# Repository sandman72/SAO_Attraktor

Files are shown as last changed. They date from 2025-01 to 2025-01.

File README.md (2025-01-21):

# SAO_Attraktor
Attraktor Logo as a SAO (Shitty / Supercon Add On)

Runs pixel animations on the Attraktor SAO Badge's 42 (! of course) LEDs

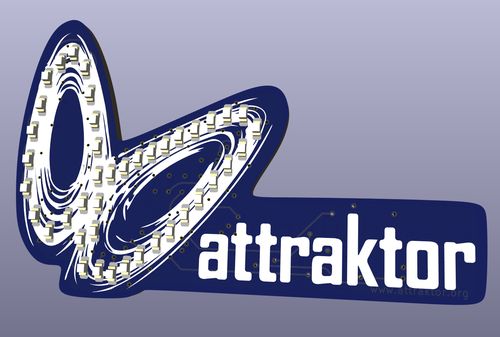
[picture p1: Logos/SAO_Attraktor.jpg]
SAO_Front

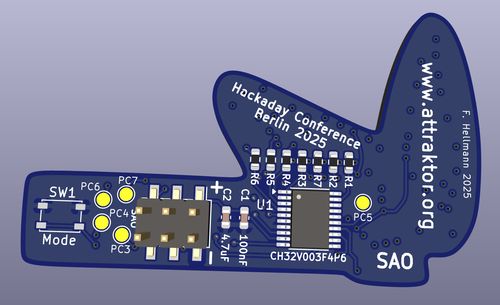
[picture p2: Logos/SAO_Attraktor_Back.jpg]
SAO_Back


KiCAD 8.0 Project with Schematics, PCB, Gerbers and Testcode 
for the Attraktor SAO PCB we show at the Hackaday Conference 2025.

Runs pixel animations on the Attraktor SAO Badge's 42 (! of course) LEDs

The Arduino code works with the following CH32V003 MCUs from the board manager:
  - CH32 MCU EVT Boards 1.0.4 or later (WCHLinkRV driver)
  - or WCH32 Boards 0.0.2 (WinUSB driver) 

Upload needs the CH32V003 WCH-LinkE dongle in RISC-V mode.

For the SAO Board to work correctly you need to reflash the MCU 
with the WCH-LinkUtility once to disable the NRST functionality on pin PD7:

  "Disable mul-func, PD7 is used for IO func"

Beware that the Eval Boards use pin PA1 and PA2 for external clock crystal 
and PD7 for Reset and therefore cannot be used for testing. Pin PD1 is 
used for programming via SWDIO

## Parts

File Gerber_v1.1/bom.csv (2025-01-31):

Designator | Footprint | Quantity | Value | LCSC Part #
C1 | 0603 | 1 | 100nF
C2 | 0603 | 1 | 4.7uF
D1, D10, D11, D12, D13, D14, D15, D16, D17, D18, D19, D2, D20, D21, D22, D23, D24, D25, D26, D27, D28, D29, D3, D30, D31, D32, D33, D34, D35, D36, D37, D38, D39, D4, D40, D41, D42, D5, D6, D7, D8, D9 | 0603 | 42 | LED
J1 | PinHeader_2x03_P2.54mm_Vertical_SMD | 1 | SAO
PC3 | TestPoint_Pad_D1.5mm | 1 | PC3
PC4 | TestPoint_Pad_D1.5mm | 1 | PC4
PC5 | TestPoint_Pad_D1.5mm | 1 | PC5
PC6 | TestPoint_Pad_D1.5mm | 1 | PC6
PC7 | TestPoint_Pad_D1.5mm | 1 | PC7
R1, R2, R3, R4, R5, R6, R7 | 0603 | 7 | 1K
SW1 | SW_SPST_PTS810 | 1 | Mode
U1 | TSSOP-20_4.4x6.5mm_P0.65mm | 1 | CH32V003F4P6

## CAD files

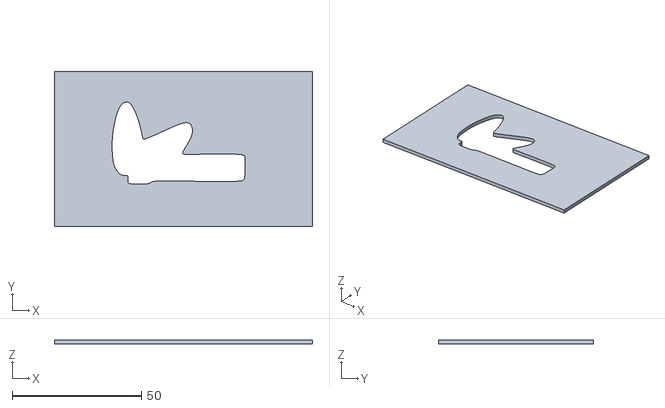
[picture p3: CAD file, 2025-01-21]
SAO_PCB_Stencil_Holder.stl
100.0 x 60.0 x 1.60

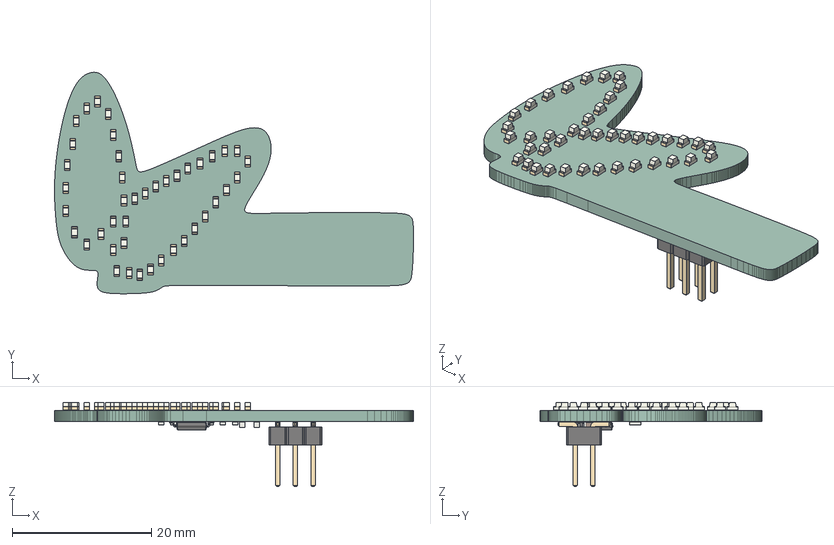
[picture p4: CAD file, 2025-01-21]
SAO_Attraktor.step
51.6 x 31.8 x 12.1 mm
LED_0603_1608Metric x 42
R_0603_1608Metric x 7
PinHeader_2x03_P254mm_Vertical_SMD
C_0603_1608Metric x 2
TSSOP_20_44x65mm_P065mm
SAO_Attraktor_PCB

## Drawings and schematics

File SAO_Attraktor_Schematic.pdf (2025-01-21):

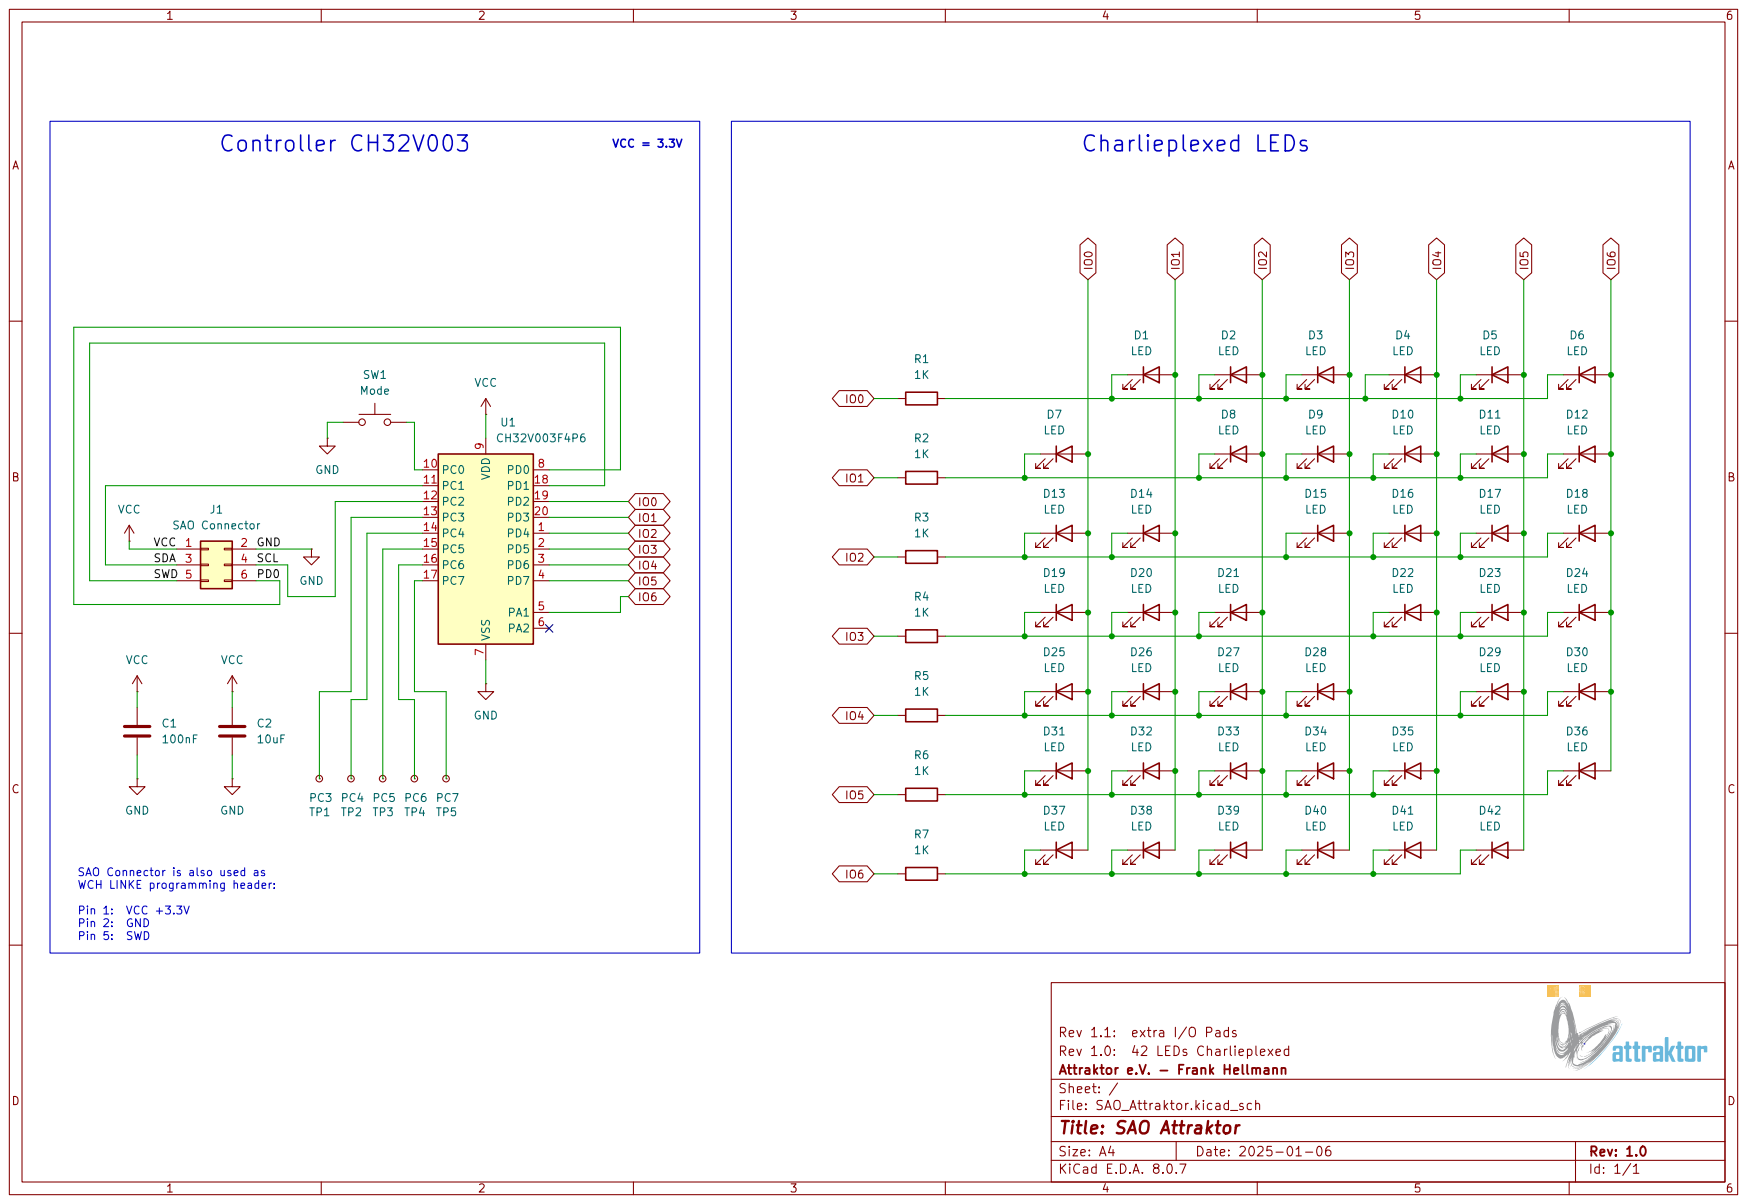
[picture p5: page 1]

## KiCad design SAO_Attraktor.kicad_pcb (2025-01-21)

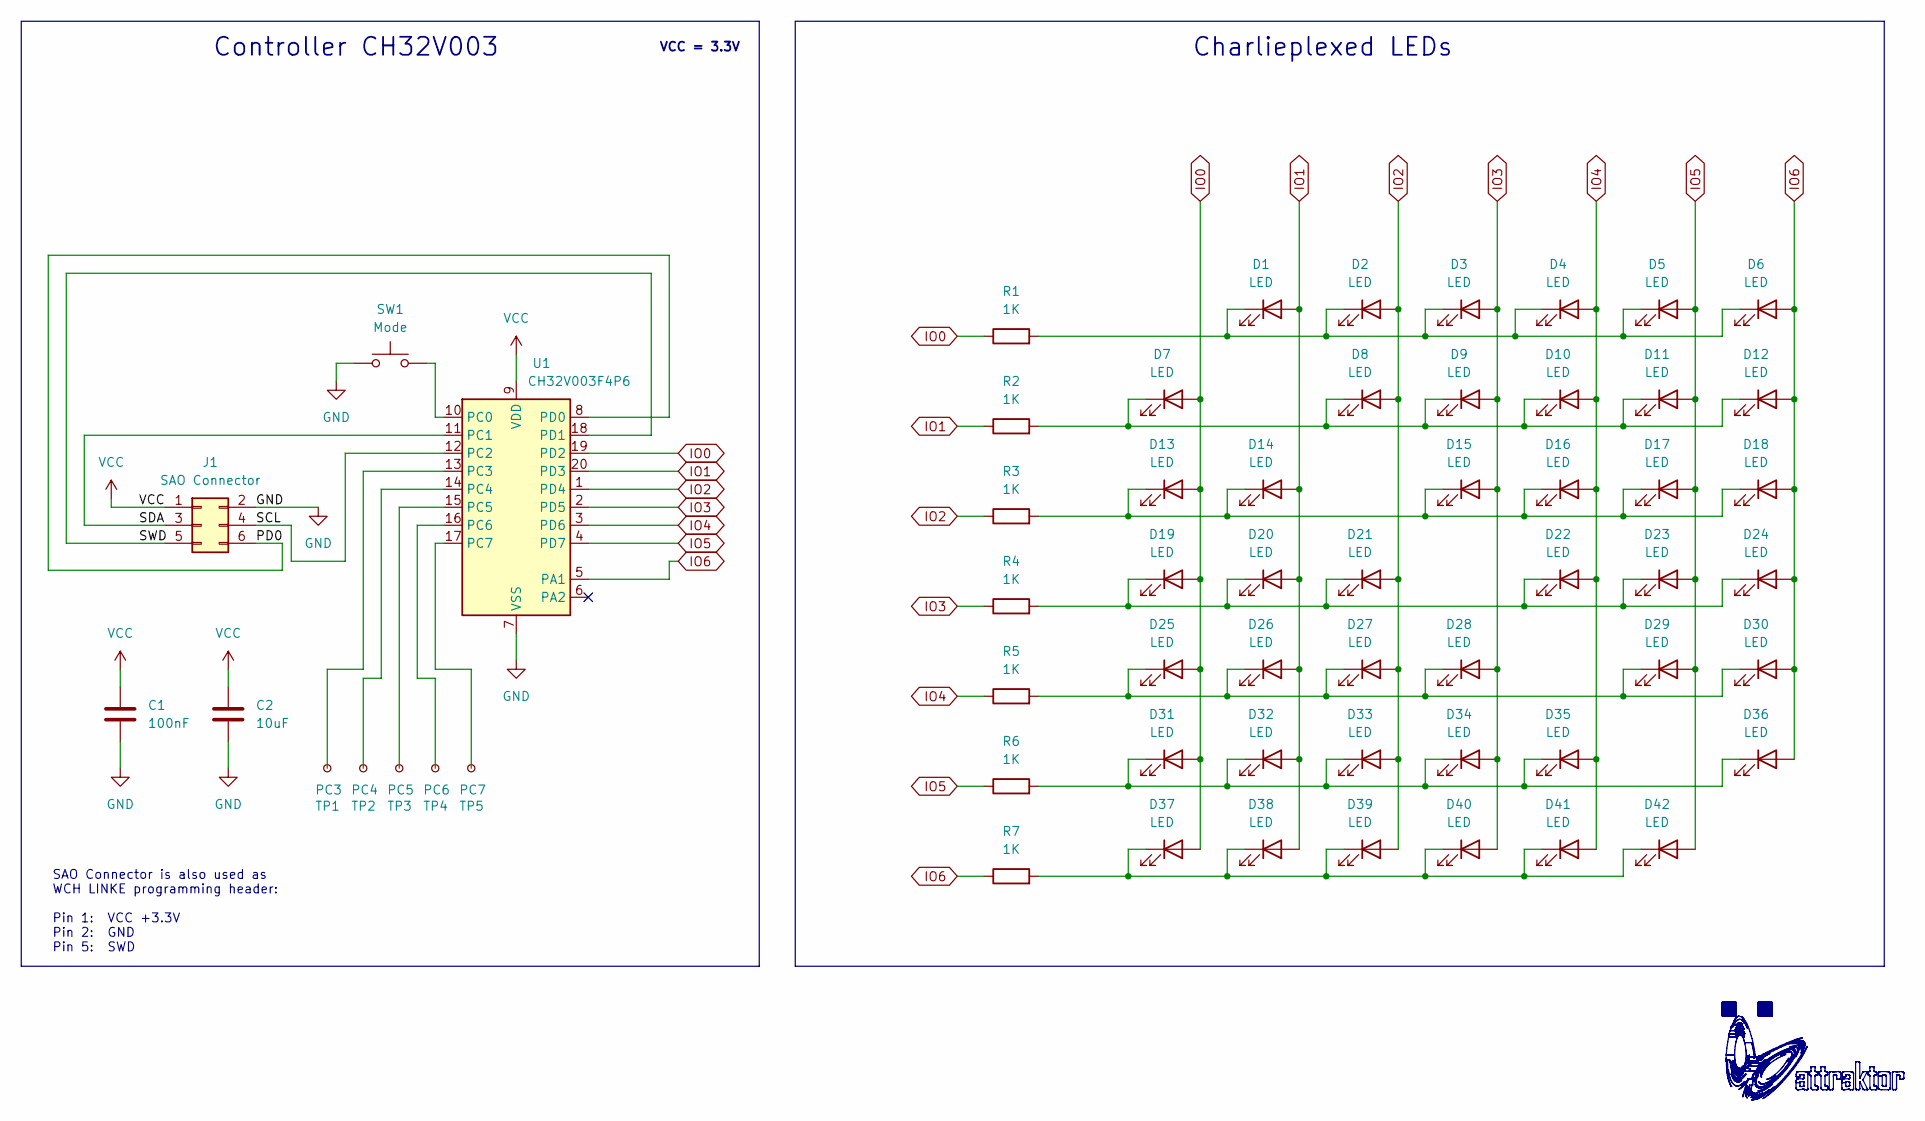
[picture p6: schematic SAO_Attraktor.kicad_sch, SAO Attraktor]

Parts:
C1: 100nF; C_0603_1608Metric
C2: 10uF; C_0603_1608Metric
D1, D2, D3, D4, D5, D6, D7, D8, D9, D10, D11, D12, D13, D14, D15, D16, D17, D18, D19, D20, D21, D22, D23, D24, D25, D26, D27, D28, D29, D30, D31, D32, D33, D34, D35, D36, D37, D38, D39, D40, D41, D42: LED; LED_0603_1608Metric
J1: SAO Connector; PinHeader_2x03_P2.54mm_Vertical_SMD
R1, R2, R3, R4, R5, R6, R7: 1K; R_0603_1608Metric
SW1: Mode; SW_SPST_PTS810
TP1: PC3; TestPoint_Pad_D1.5mm
TP2: PC4; TestPoint_Pad_D1.5mm
TP3: PC5; TestPoint_Pad_D1.5mm
TP4: PC6; TestPoint_Pad_D1.5mm
TP5: PC7; TestPoint_Pad_D1.5mm
U1: CH32V003F4P6; TSSOP-20_4.4x6.5mm_P0.65mm

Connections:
/PD0: J1.6, U1.8 (PD0)
/SCL: J1.4, U1.12 (PC2)
/SDA: J1.3, U1.11 (PC1)
/SWD: J1.5, U1.18 (PD1)
GND: C1.2, C2.2, J1.2, SW1.1, U1.7 (VSS)
IO0: D7.2 (A), D13.2 (A), D19.2 (A), D25.2 (A), D31.2 (A), D37.2 (A), R1.1, U1.19 (PD2)
IO1: D1.2 (A), D14.2 (A), D20.2 (A), D26.2 (A), D32.2 (A), D38.2 (A), R2.1, U1.20 (PD3)
IO2: D2.2 (A), D8.2 (A), D21.2 (A), D27.2 (A), D33.2 (A), D39.2 (A), R3.1, U1.1 (PD4)
IO3: D3.2 (A), D9.2 (A), D15.2 (A), D28.2 (A), D34.2 (A), D40.2 (A), R4.1, U1.2 (PD5)
IO4: D4.2 (A), D10.2 (A), D16.2 (A), D22.2 (A), D35.2 (A), D41.2 (A), R5.1, U1.3 (PD6)
IO5: D5.2 (A), D11.2 (A), D17.2 (A), D23.2 (A), D29.2 (A), D42.2 (A), R6.1, U1.4 (PD7)
IO6: D6.2 (A), D12.2 (A), D18.2 (A), D24.2 (A), D30.2 (A), D36.2 (A), R7.1, U1.5 (PA1)
unnamed: D1.1 (K), D2.1 (K), D3.1 (K), D4.1 (K), D5.1 (K), D6.1 (K), R1.2
unnamed: D7.1 (K), D8.1 (K), D9.1 (K), D10.1 (K), D11.1 (K), D12.1 (K), R2.2
unnamed: D13.1 (K), D14.1 (K), D15.1 (K), D16.1 (K), D17.1 (K), D18.1 (K), R3.2
unnamed: D19.1 (K), D20.1 (K), D21.1 (K), D22.1 (K), D23.1 (K), D24.1 (K), R4.2
unnamed: D25.1 (K), D26.1 (K), D27.1 (K), D28.1 (K), D29.1 (K), D30.1 (K), R5.2
unnamed: D31.1 (K), D32.1 (K), D33.1 (K), D34.1 (K), D35.1 (K), D36.1 (K), R6.2
unnamed: D37.1 (K), D38.1 (K), D39.1 (K), D40.1 (K), D41.1 (K), D42.1 (K), R7.2
unnamed: SW1.2, U1.10 (PC0)
unnamed 20: TP1.1, U1.13 (PC3); also elsewhere on the board
unnamed 21: TP2.1, U1.14 (PC4); also elsewhere on the board
unnamed 22: TP3.1, U1.15 (PC5); also elsewhere on the board
unnamed 23: TP4.1, U1.16 (PC6); also elsewhere on the board
unnamed 24: TP5.1, U1.17 (PC7); also elsewhere on the board
VCC: C1.1, C2.1, J1.1, U1.9 (VDD)

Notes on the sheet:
Charlieplexed LEDs
VCC = 3.3V
Controller CH32V003
SAO Connector is also used as WCH LINKE programming header: Pin 1: VCC +3.3V Pin 2: GND Pin 5: SWD

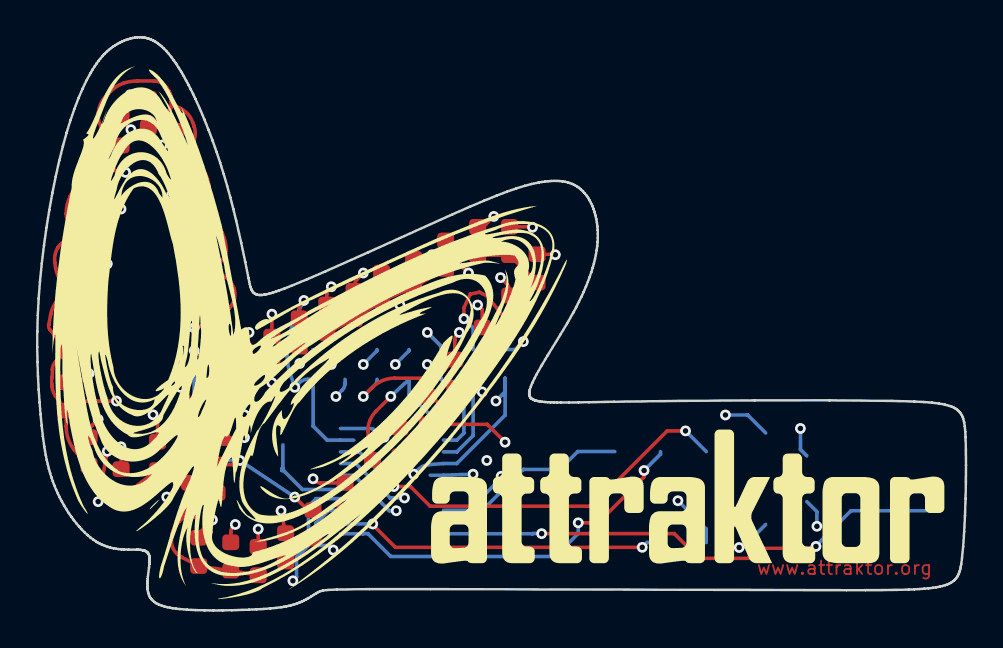
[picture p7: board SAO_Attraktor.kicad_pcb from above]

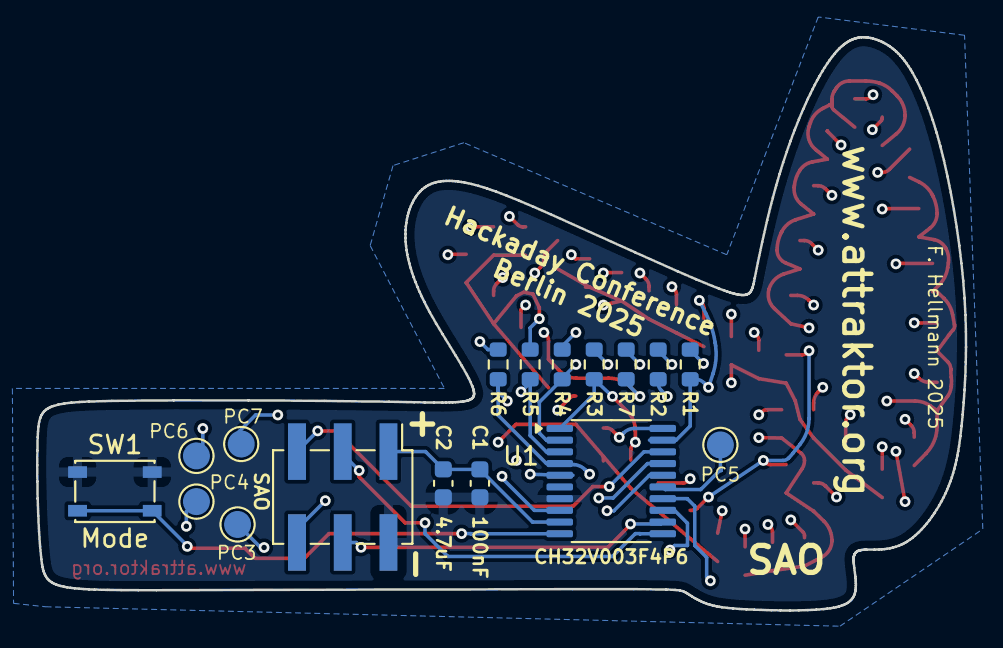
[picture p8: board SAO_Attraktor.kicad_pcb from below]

Board: 4 copper layers, 51.6 x 31.8 mm, 59 parts (17 on the bottom side), 26 nets.

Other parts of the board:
PC3: PC3; TestPoint_Pad_D1.5mm
PC4: PC4; TestPoint_Pad_D1.5mm
PC5: PC5; TestPoint_Pad_D1.5mm
PC6: PC6; TestPoint_Pad_D1.5mm
PC7: PC7; TestPoint_Pad_D1.5mm

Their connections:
unnamed 20: PC3.1; also elsewhere on the board
unnamed 21: PC4.1; also elsewhere on the board
unnamed 22: PC5.1; also elsewhere on the board
unnamed 23: PC6.1; also elsewhere on the board
unnamed 24: PC7.1; also elsewhere on the board

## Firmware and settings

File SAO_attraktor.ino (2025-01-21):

/*
  Runs the pixel animation on the Attraktor SAO Badge

  modified 10 Jan 2025
  by Frank Hellmann

  This example code is in the public domain.

  Works with CH32 MCU EVT Boards 1.0.4 or later (WCHLinkRV driver) or WCH32 Boards 0.0.2 (WinUSB driver)

  For the SAO Board you need to reflash the MCU with the WCH-LinkUtility once to disable the NRST functionality on pin PD7:
  "Disable mul-func, PD7 is used for IO func"

  Beware that the Eval Boards use pin PA1 and PA2 for external clock crystal and PD7 for Reset and therefore cannot be used for testing

  Pin PD1 is used for programming via SWDIO

*/

int count = 0;
int mode = 1;

// our output pins for charlieplexing on SAO board
int led_pins[] = {PD2,PD3,PD4,PD5,PD6,PD7,PA1};
int button = PD0;

// clear digital pins
void clear_led() {
  for (int i=0; i<7; i++) { 
    pinMode(led_pins[i], INPUT); 
  }
}

void set_led(int led){
  led=1+led+led/7;
  int row = led/7;
  int col = led%7;
  pinMode(led_pins[row], OUTPUT);
  digitalWrite(led_pins[row], LOW); 
  pinMode(led_pins[col], OUTPUT);
  digitalWrite(led_pins[col], HIGH); 
 }

// the setup function runs once when you press reset or power the board
void setup() {
  // disable external clock and free up pin PA1
  AFIO->PCFR1 = AFIO->PCFR1 & 0xFFFF7FFF;
  // initialize digital pins as floating, eg. input.
  clear_led();
  // initialize button input for mode change
  pinMode(D0,INPUT);
}

// the loop function runs over and over again forever
void loop() {
  clear_led();
  set_led(count++);
  if (count>41) {
    count=0;
    if(mode>1){
      clear_led();
      delay(random(10000));
    }
  }
  if (mode>0) {
    if (count<22) { delayMicroseconds(1500 + count*500); }
    if (count>21) { delayMicroseconds(1500 + (42-count) * 500); }
    //delayMicroseconds(3500);
  }
}

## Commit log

2025-01-21 Initial commit of Version 1.1
    Version 1.1 adds extra breakout pads for I/O Pins PC3-PC7
    [SAO_Attraktor-B_Cu.gbr, SAO_Attraktor-B_Mask.gbr, SAO_Attraktor-B_Silkscreen.gbr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]
2025-01-21 Arduino Demo Code and Documentation
2025-01-31 Added Position and BOM files
    [bom.csv, designators.csv, positions.csv]
